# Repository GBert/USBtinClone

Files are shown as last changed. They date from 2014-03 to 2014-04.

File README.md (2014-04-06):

USBtinClone
===========

This git contains hard- and software of a USBtin clone.
Original version:

http://www.fischl.de/usbtin/

This is a CAN2USB adapter which uses the SLCAN API. The SLCAN protocol doesn't
have the fastest API (all CAN frames are transfered into human readable ASCII),
but well known. Even Linux provides a kernel module for SocketCAN. 
The SLCAN API is also known as Lawicel protocol.

Difference to the orginal
-------------------------

The original version uses only through hole components which makes it easy to
solder. But the original version does have some little drawbacks IMHO.
So I started to make a clone:

- added galvanic isolation - no special hardware needed (eg TI ISO1050)
- fits into 5cm x 5cm square for cheap PCB
- one layer design for homebrew (only one brass jumper)

but still untested ...

Programming
-----------

First step is to programm the bootloader on the PIC18F14K50.
If you don't own a PIC programmer use a cheap USB cp2104
to flash the bootloader:

https://github.com/GBert/CP2104_GPIO

and then programm the usbtin code with:

http://code.google.com/p/mphidflash/

### Usage

```
modprobe can
modprobe can-raw
modprobe can-dev 
modprobe slcan
# configure 1Mbit  
slcand -o -s8 -S 3000000 ttyACM0 can0
 ifconfig -a
can0      Link encap:UNSPEC  Hardware Adresse 00-00-00-00-00-00-00-00-00-00-00-00-00-00-00-00  
          NOARP  MTU:16  Metrik:1
          RX packets:0 errors:0 dropped:0 overruns:0 frame:0
          TX packets:0 errors:0 dropped:0 overruns:0 carrier:0
          Kollisionen:0 Sendewarteschlangenlänge:10 
          RX-Bytes:0 (0.0 B)  TX-Bytes:0 (0.0 B)

ifconfig can0 up
ip -s -d link show can0
4: can0: <NOARP,UP,LOWER_UP> mtu 16 qdisc pfifo_fast state UNKNOWN mode DEFAULT qlen 10
    link/can 
    RX: bytes  packets  errors  dropped overrun mcast   
    0          0        0       0       0       0      
    TX: bytes  packets  errors  dropped carrier collsns 
    0          0        0       0       0       0     
```

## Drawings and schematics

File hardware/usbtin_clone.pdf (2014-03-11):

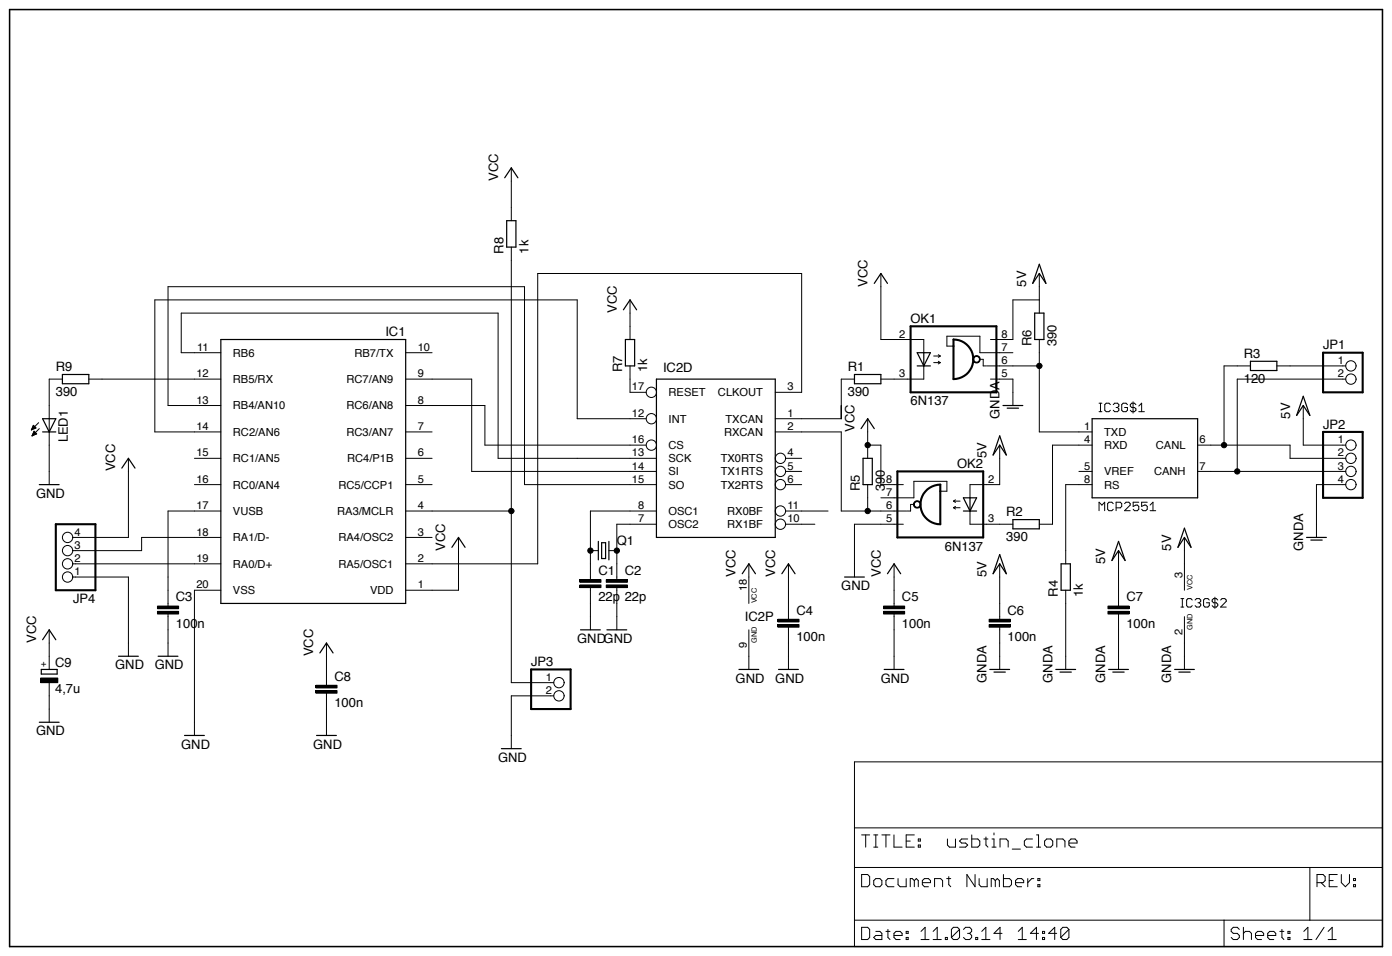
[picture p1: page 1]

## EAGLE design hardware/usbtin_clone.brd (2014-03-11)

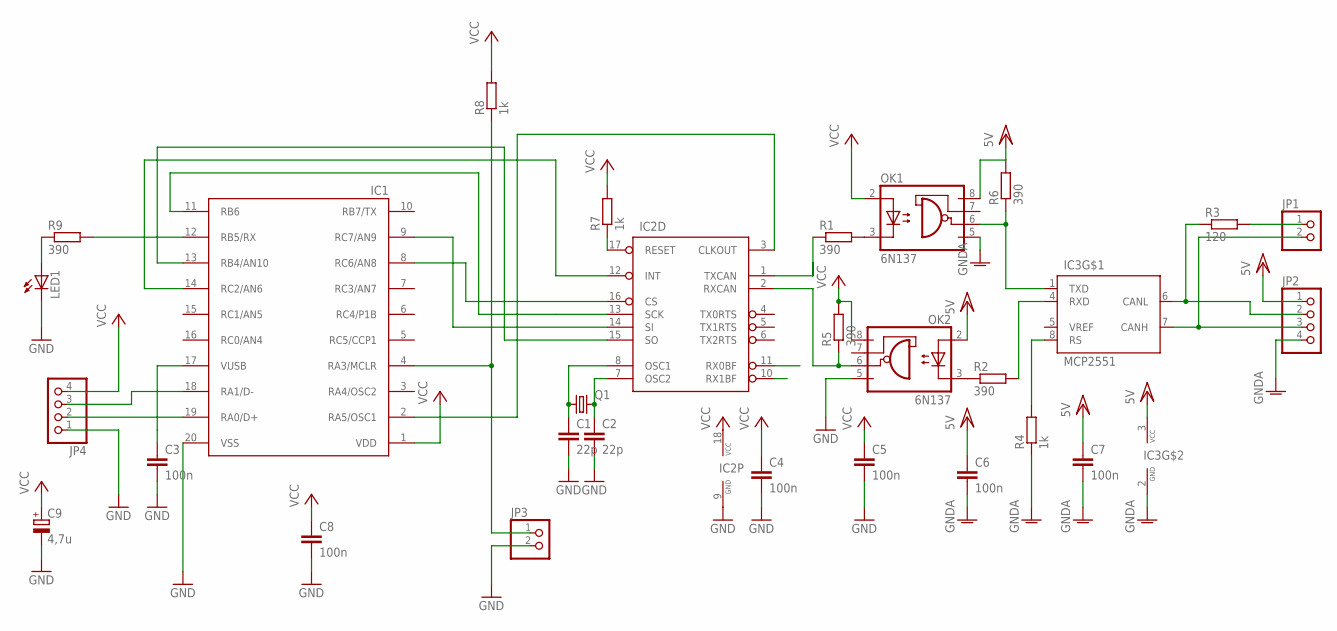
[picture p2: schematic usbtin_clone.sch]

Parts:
C1, C2: 22p; C025-025X050
C3, C4, C5, C6, C7, C8: 100n; C025-025X050
C9: 4,7u; E2,5-5
IC1: 18F14K50; DIL20
IC2: MCP2515P; DIL18
IC3: MCP2551; DIL08
JP1, JP3: PINHD-1X2; 1X02
JP2, JP4: PINHD-1X4; 1X04
LED1: LED3MM
OK1, OK2: 6N137; DIL08
Q1: CRYSTALHC49S; HC49/S
R1, R2, R5, R6, R9: 390; 0204/7
R3: 120; 0204/7
R4, R7, R8: 1k; 0204/7

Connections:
GND: C1.2, C2.2, C3.2, C4.2, C5.2, C8.2, C9.-, IC1.20 (VSS), IC2.9 (GND), JP3.2, JP4.1, LED1.K (C), OK2.5 (GND)
GNDA: C6.2, C7.2, IC3.2 (GND), JP2.4, OK1.5 (GND), R4.1
unnamed: C1.1, IC2.8 (OSC1), Q1.1
unnamed: C2.1, IC2.7 (OSC2), Q1.2
unnamed: OK1.3 (C), R1.2
unnamed: IC2.2 (RXCAN), OK2.6 (VO), R5.1
unnamed: IC2.1 (TXCAN), R1.1
unnamed: IC3.1 (TXD), OK1.6 (VO), R6.1
unnamed: OK2.3 (C), R2.1
unnamed: IC3.4 (RXD), R2.2
unnamed: IC3.6 (CANL), JP2.2, R3.1
unnamed: JP1.1, R3.2
unnamed: IC3.7 (CANH), JP1.2, JP2.3
unnamed: IC3.8 (RS), R4.2
unnamed: C3.1, IC1.17 (VUSB)
unnamed: IC2.17 (RESET), R7.1
unnamed: IC1.2 (RA5/OSC1), IC2.3 (CLKOUT)
unnamed: IC1.14 (RC2/AN6), IC2.12 (INT)
unnamed: IC1.4 (RA3/MCLR), JP3.1, R8.1
unnamed: IC1.19 (RA0/D+), JP4.2
unnamed: IC1.18 (RA1/D-), JP4.3
unnamed: IC1.12 (RB5/RX), R9.2
unnamed: LED1.A, R9.1
unnamed: IC1.8 (RC6/AN8), IC2.16 (CS)
unnamed: IC1.11 (RB6), IC2.13 (SCK)
unnamed: IC1.9 (RC7/AN9), IC2.14 (SI)
unnamed: IC1.13 (RB4/AN10), IC2.15 (SO)
VCC: C4.1, C5.1, C8.1, C9.+, IC1.1 (VDD), IC2.18 (VCC), JP4.4, OK1.2 (A), OK2.8 (VCC), R5.2, R7.2, R8.2
VCC/2: C6.1, C7.1, IC3.3 (VCC), JP2.1, OK1.8 (VCC), OK2.2 (A), R6.2

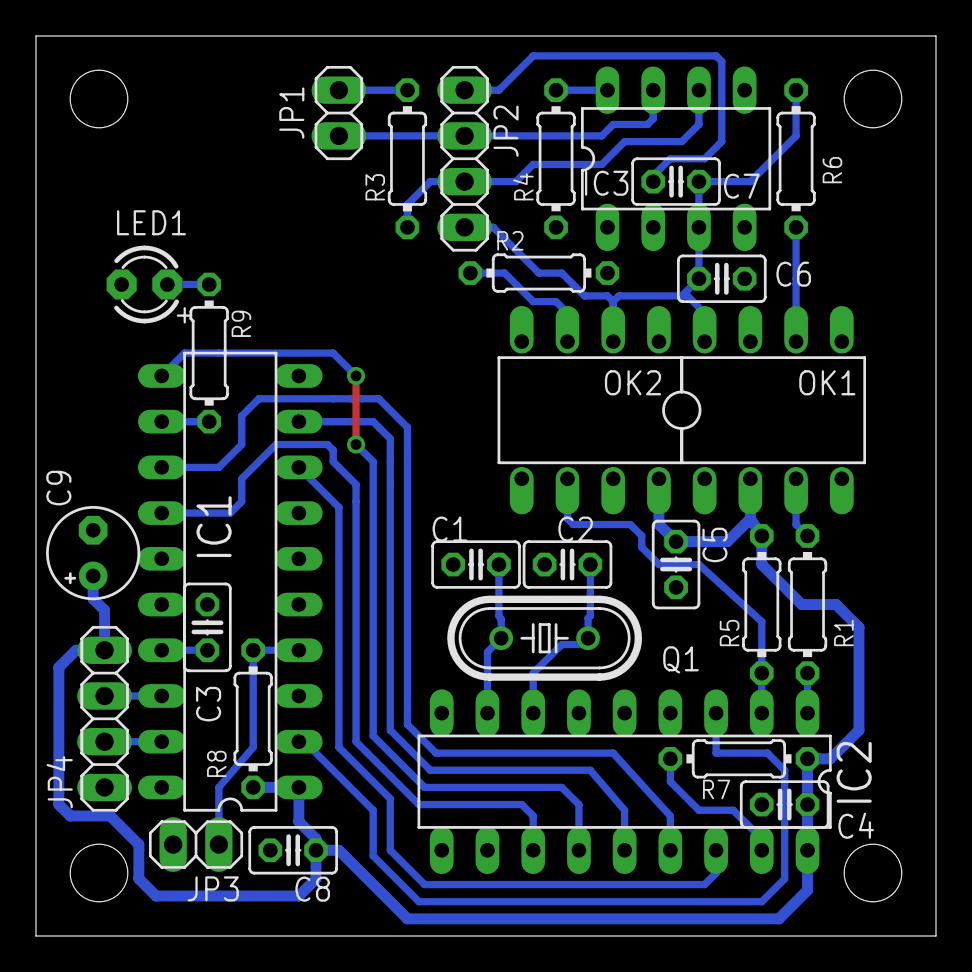
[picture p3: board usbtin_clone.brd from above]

Board: 2 copper layers, 50.0 x 50.0 mm, 29 parts (0 on the bottom side), 29 nets.

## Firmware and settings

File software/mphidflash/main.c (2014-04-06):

/****************************************************************************
 File        : main.c
 Description : Main source file for 'mphidflash,' a simple command-line tool for
               communicating with Microchips USB HID-Bootloader and downloading new
               firmware. 

 History     : 2009-02-19  Phillip Burgess
                 * Initial implementation
               2009-12-26  Thomas Fischl, Dominik Fisch (www.FundF.net)
                 * Renamed 'ubw32' to 'mphidflash'
               
 License     : Copyright (C) 2009 Phillip Burgess
               Copyright (C) 2009 Thomas Fischl, Dominik Fisch (www.FundF.net)

               This file is part of 'mphidflash' program.

               'mphidflash' is free software: you can redistribute it and/or
               modify it under the terms of the GNU General Public License
               as published by the Free Software Foundation, either version
               3 of the License, or (at your option) any later version.

               'mphidflash' is distributed in the hope that it will be useful,
               but WITHOUT ANY WARRANTY; without even the implied warranty
               of MERCHANTABILITY or FITNESS FOR A PARTICULAR PURPOSE.
               See the GNU General Public License for more details.

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
 ****************************************************************************/

#include <stdio.h>
#include <string.h>
#include "mphidflash.h"

extern unsigned char * usbBuf;  /* In usb code */

/* Program's actions aren't necessarily performed in command-line order.
   Bit flags keep track of options set or cleared during input parsing,
   then are singularly checked as actions are performed.  Some actions
   (such as writing) don't have corresponding bits here; certain non-NULL
   string values indicate such actions should occur. */
#define ACTION_UNLOCK (1 << 0)
#define ACTION_ERASE  (1 << 1)
#define ACTION_VERIFY (1 << 2)
#define ACTION_RESET  (1 << 3)

/****************************************************************************
 Function    : main
 Description : mphidflash program startup; parse command-line input and issue
               commands as needed; return program status.
 Returns     : int  0 on success, else various numeric error codes.
 ****************************************************************************/
int main(
  int   argc,
  char *argv[])
{
	char        *hexFile   = NULL,
	             actions   = ACTION_VERIFY,
	             eol;        /* 1 = last command-line arg */
	ErrorCode    status    = ERR_NONE;
	int          i;
	unsigned int vendorID  = 0x04d8,
	             productID = 0x003c;

	const char * const errorString[ERR_EOL] = {
		"Missing or malformed command-line argument",
		"Command not recognized",
		"Device not found (is device attached and in Bootloader mode?)",
		"USB initialization failed (phase 1)",
		"USB initialization failed (phase 2)",
		"Device could not be opened for I/O",
		"USB write error",
		"USB read error",
		"Could not open hex file for input",
		"Could not query hex file size",
		"Could not map hex file to memory",
		"Unrecognized or invalid hex file syntax",
		"Bad end-of-line checksum in hex file",
		"Unsupported record type in hex file",
		"Verify failed"
	};

	/* To create a sensible sequence of operations, all command-line
	   input is processed prior to taking any actions.  The sequence
	   of actions performed may not always directly correspond to the
	   order or quantity of input; commands follow precedence, not
	   input order.  For example, the action corresponding to the "-u"
	   (unlock) command must take place early on, before any erase or
	   write operations, even if specified late on the command line;
	   conversely, "-r" (reset) should always be performed last
	   regardless of input order.  In the case of duplicitous
	   commands (e.g. if multiple "-w" (write) commands are present),
	   only the last one will take effect.

	   The precedence of commands (first to last) is:

	   -v and -p <hex>  USB vendor and/or product IDs
	   -u               Unlock configuration memory
	   -e               Erase program memory
	   -n               No verify after write
	   -w <file>        Write program memory
	   -r               Reset */

	for(i=1;(i < argc) && (ERR_NONE == status);i++) {
		eol = (i >= (argc - 1));
		if(!strncasecmp(argv[i],"-v",2)) {
			if(eol || (1 != sscanf(argv[++i],"%x",&vendorID)))
				status = ERR_CMD_ARG;
		} else if(!strncasecmp(argv[i],"-p",2)) {
			if(eol || (1 != sscanf(argv[++i],"%x",&productID)))
				status = ERR_CMD_ARG;
		} else if(!strncasecmp(argv[i],"-u",2)) {
			actions |= ACTION_UNLOCK;
		} else if(!strncasecmp(argv[i],"-e",2)) {
			actions |= ACTION_ERASE;
		} else if(!strncasecmp(argv[i],"-n",2)) {
			actions &= ~ACTION_VERIFY;
		} else if(!strncasecmp(argv[i],"-w",2)) {
			if(eol) {
				status   = ERR_CMD_ARG;
			} else {
				hexFile  = argv[++i];
				actions |= ACTION_ERASE;
			}
		} else if(!strncasecmp(argv[i],"-r",2)) {
			actions |= ACTION_RESET;
		} else if(!strncasecmp(argv[i],"-h",2) ||
		          !strncasecmp(argv[i],"-?",2)) {
			(void)printf(
"mphidflash v%d.%d: a Microchip HID Bootloader utility\n"
"Option     Description                                      Default\n"
"-------------------------------------------------------------------------\n"
"-w <file>  Write hex file to device (will erase first)      None\n"
"-e         Erase device code space (implicit if -w)         No erase\n"
"-r         Reset device on program exit                     No reset\n"
"-n         No verify after write                            Verify on\n"
"-u         Unlock configuration memory before erase/write   Config locked\n"
"-v <hex>   USB device vendor ID                             04d8\n"
"-p <hex>   USB device product ID                            003c\n"
"-h or -?   Help\n", VERSION_MAIN, VERSION_SUB);
			return 0;
		} else {
			status = ERR_CMD_UNKNOWN;
		}
	}

	/* After successful command-line parsage, find/open USB device. */

	if((ERR_NONE == status) &&
	   (ERR_NONE == (status = usbOpen(vendorID,productID)))) {

		/* And start doing stuff... */

		(void)printf("USB HID device found\n");
		usbBuf[0] = QUERY_DEVICE;
		if(ERR_NONE == (status = usbWrite(1,1))) {
			int j;

                        (void)printf("  Device family: ");
			unsigned char deviceFamily = usbBuf[2];
			switch (deviceFamily)
			{
				case DEVICE_FAMILY_PIC18:
					hexSetBytesPerAddress(1);
					(void)printf("PIC18\n");
					break;
				case DEVICE_FAMILY_PIC24:
					hexSetBytesPerAddress(2);
					(void)printf("PIC24\n");
					break;
				case DEVICE_FAMILY_PIC32:
					hexSetBytesPerAddress(1);
					(void)printf("PIC32\n");
					break;
				default:
					hexSetBytesPerAddress(1);
					(void)printf("Unknown. Bytes per address set to 1.\n");
					break;
			}

                        (void)printf("  Program memory: ");
			for(i=1,j=3;usbBuf[j]!=TypeEndOfTypeList;j+=9,i++) {
			  if(usbBuf[j] == TypeProgramMemory)
			    (void)printf("%d bytes free. ",bufRead32(j + 5));
			}
			(void)putchar('\n');

		}

		if((ERR_NONE == status) && (actions & ACTION_UNLOCK)) {
			(void)puts("Unlocking configuration memory...");
			usbBuf[0] = UNLOCK_CONFIG;
			usbBuf[1] = UNLOCKCONFIG;
			status    = usbWrite(2,0);
		}

		/* Although the next actual operation is ACTION_ERASE,
		   if we anticipate hex-writing in a subsequent step,
                   attempt opening file now so we can display any error
		   message quickly rather than waiting through the whole
		   erase operation (it's usually a simple filename typo). */
		if((ERR_NONE == status) && hexFile &&
		   (ERR_NONE != (status = hexOpen(hexFile))))
			hexFile = NULL;  /* Open or mmap error */

		if((ERR_NONE == status) && (actions & ACTION_ERASE)) {
			(void)puts("Erasing...");
			usbBuf[0] = ERASE_DEVICE;
			status    = usbWrite(1,0);
			/* The query here isn't needed for any technical
			   reason, just makes the presentation better.
			   The ERASE_DEVICE command above returns
			   immediately...subsequent commands can be made
			   but will pause until the erase cycle completes.
			   So this query just keeps the "Writing" message
			   or others from being displayed prematurely. */
			usbBuf[0] = QUERY_DEVICE;
			status    = usbWrite(1,1);
		}

		if(hexFile) {
			if(ERR_NONE == status) {
			  (void)printf("Writing hex file '%s':",hexFile);
			  status = hexWrite((actions & ACTION_VERIFY) != 0);
			  (void)putchar('\n');
			}
			hexClose();
		}

		if((ERR_NONE == status) && (actions & ACTION_RESET)) {
			(void)puts("Resetting device...");
			usbBuf[0] = RESET_DEVICE;
			status = usbWrite(1,0);
		}

		usbClose();
	}

	if(ERR_NONE != status) {
		(void)printf("%s Error",argv[0]);
		if(status <= ERR_EOL)
			(void)printf(": %s\n",errorString[status - 1]);
		else
			(void)puts(" of indeterminate type.");
	}

	return (int)status;
}

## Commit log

2014-03-03 initial commit of Eagle design
    [usbtin_clone.brd, usbtin_clone.sch]
2014-03-04 add text on bottom layer to identify mirroring
    [usbtin_clone.brd]
2014-03-04 add comment about diy mod to BRD file
    [usbtin_clone.brd]
2014-03-04 revert deleting
    [usbtin_clone.brd]
2014-03-04 minor BRD changes
    [usbtin_clone.brd]
2014-03-09 add vallues to schematic
    [usbtin_clone.sch]
2014-03-11 5V clearance
    [usbtin_clone.sch]
2014-03-11 grr - CAN TX/RX fault
    [usbtin_clone.brd, usbtin_clone.sch]
